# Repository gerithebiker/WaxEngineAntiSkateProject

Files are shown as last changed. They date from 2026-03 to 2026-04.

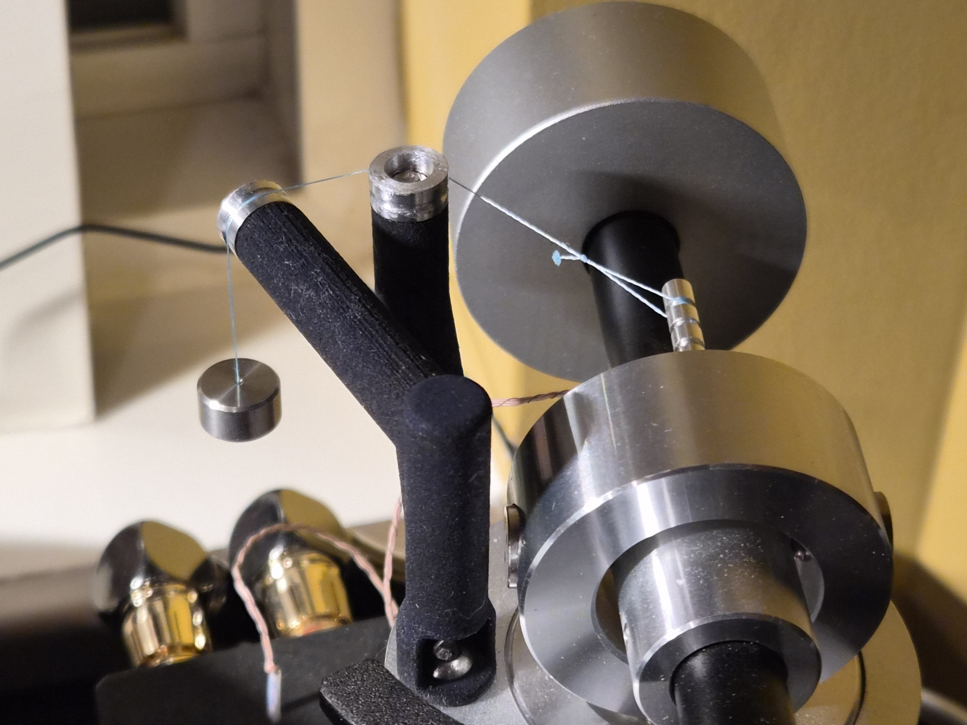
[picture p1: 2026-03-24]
images/completed.jpg

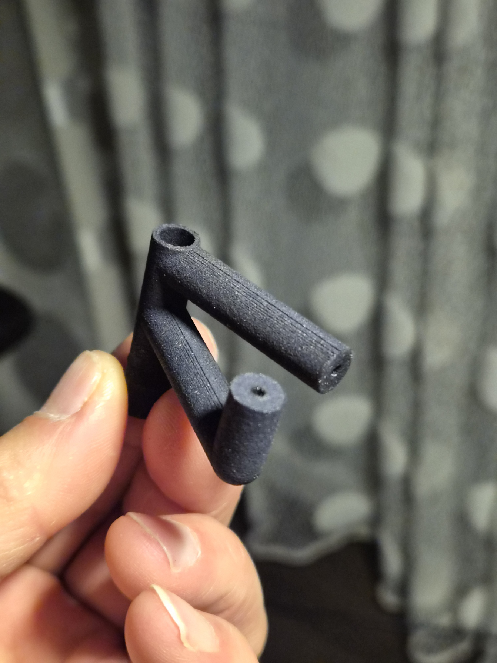
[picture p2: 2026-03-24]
images/housing.jpg

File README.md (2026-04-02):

# WaxEngineAntiSkateProject
3D printable anti-skate mechanism upgrade for the Opera Consonance Wax Engine turntable. Dual-pulley, ball-bearing design replacing the original flexible wire support.

# Opera Consonance Wax Engine Anti-Skate Upgrade (3D Printable)

A 3D-printable anti-skate mechanism upgrade for the Opera Consonance Wax Engine turntable.
This design replaces the original flexible wire support with a rigid, dual-pulley, ball-bearing system for smoother and more stable operation.

---

## 🔧 Why this upgrade?

The stock anti-skate mechanism uses a thin wire to hold the counterweight.
While it works in theory, in practice it tends to flex, bend, and introduce inconsistent behavior.

Typical issues:

* Wire bending under load
* Stick-slip motion (jerky movement)
* Unpredictable anti-skate force

This upgrade solves these problems with a mechanically simple but much more stable solution.

---

## ⚙️ Design overview

* Dual-pulley system for proper line guidance
* Ball bearings for near-zero friction
* Rigid printed housing (no flex under load)
* Compact design that fits the original geometry

The vertical pulley ensures proper alignment, while the horizontal pulley handles the load — eliminating angle-related inconsistencies.

---

## 🧵 Line options

Two approaches were tested:

### 1. Human hair (yes, really 😄)

* Extremely thin
* Minimal friction
* Hard to tie and inconsistent

### 2. Braided fishing line (recommended)

* Consistent diameter
* Easy(er...) to work with
* Very strong and stable

👉 Recommendation: use the thinnest braided line available.
👉 If you don't have a special fishing line cutter, then the best way to cut is using a torch lighter. Normal scissors, knifes will _not_ work!

---

## 🔩 Bearings

Shielded (ZZ) miniature ball bearings are used in this design.

Recommended size:
- Inner diameter: 2 mm  
- Outer diameter: 5 mm  
- Width: 2.5 mm  

These are commonly referred to as **MR52ZZ bearings** and are widely available from many suppliers. You need 2 pieces.

---

## 🔧 Shafts

The bearings are mounted on simple 2 mm shafts.

These can be:
- 2 mm steel rods  
- Cut sections of drill bits  
- Any straight, rigid 2 mm metal rod  

You need 1 piece of 20-22mm long, and one 17mm long.

Make sure the shaft fits snugly and keeps the bearings aligned. If the shafts feel loose, you can glue them in place.
Just be careful — once glued, they’re not coming out easily, so treat this as a final step.

---

## 🧱 Files included

* `/AntiSkatingOnePiece.FCStd` → full FreeCAD model
* `/stl/` → ready-to-print parts
* `/images/` → reference and assembly images

---

## 🖨️ Printing notes

* Material: First I used SLS (see pics), but the surface is not really smooth, but otherwise very good.  For the second print I used UTR imagine black resin.
* Layer height: standard (0.2 mm works fine)
* No special settings required

---

## 🧾 Printing services

If you don’t have access to a 3D printer, this design can be easily ordered from most online printing services.

I used a commercial printing service ([Xometry](https://www.xometry.com)) with standard PLA settings, printed in black PLA, and the parts worked well with minimal cleanup.
Services, like JLCPCB are using different coordinate as "up", so you might need to re-create the STL files.

---

## 🔩 Assembly notes

* The holes for bearing shafts are intentionally undersized
* Drill holes to **2 mm** during assembly
* This ensures proper fit despite printing tolerances

Make sure bearings rotate freely after installation.

---

## 🎯 Result

* Smooth, continuous movement
* No stiction
* No visible flex
* Stable and predictable anti-skate behavior

---

## 🧠 Notes

This is a simple mechanical improvement — no electronics, no complex tuning — just fixing a weak point in an otherwise excellent turntable.

---

## 📎 Related article

Full write-up and background:
👉 [Opera Consonance Wax Engine Anti-Skate Modification (DIY Fix), Blog post](https://geri-in-ny.blogspot.com/2026/03/opera-consonance-wax-engine-anti-skate.html)

---

## 🤘 License

CERN-OHL-S v2 — Strongly Reciprocal Open Hardware License.

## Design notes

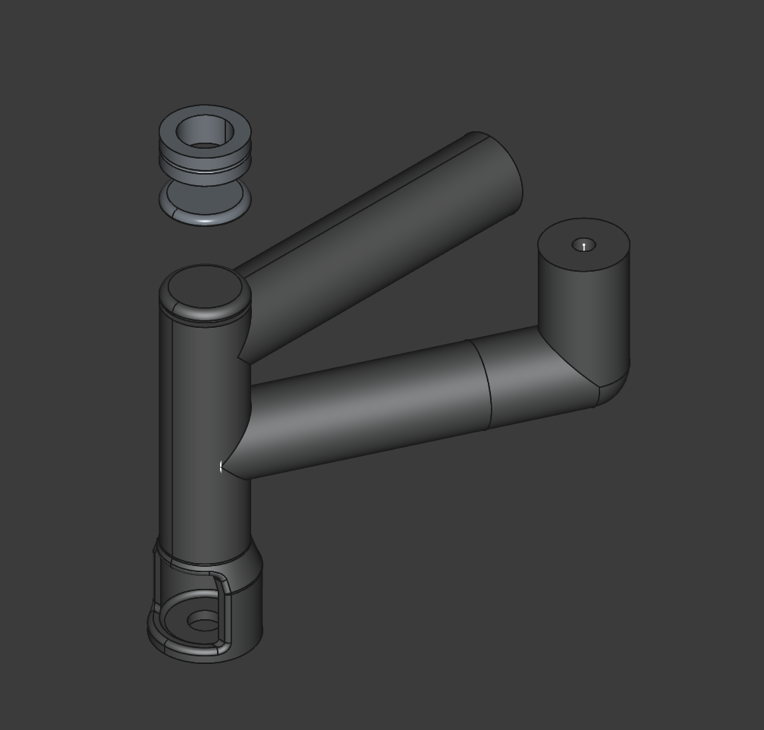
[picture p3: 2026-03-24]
images/AntiSkatingOnePiece.png

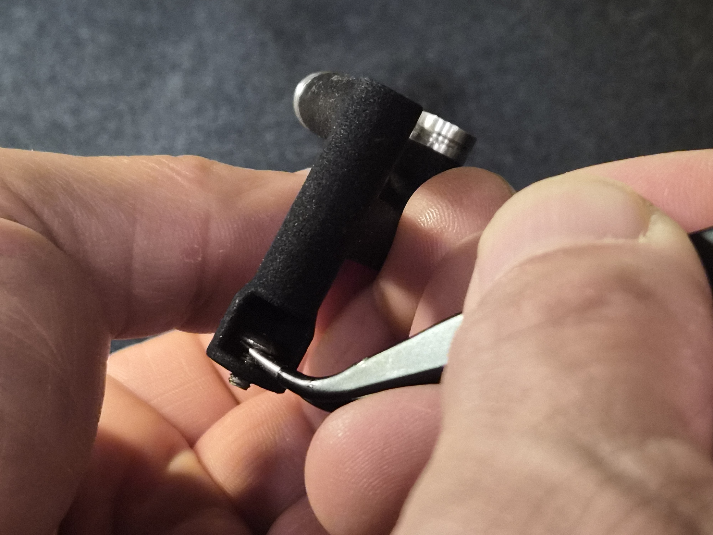
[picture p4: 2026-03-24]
images/insertingTheScrew.jpg

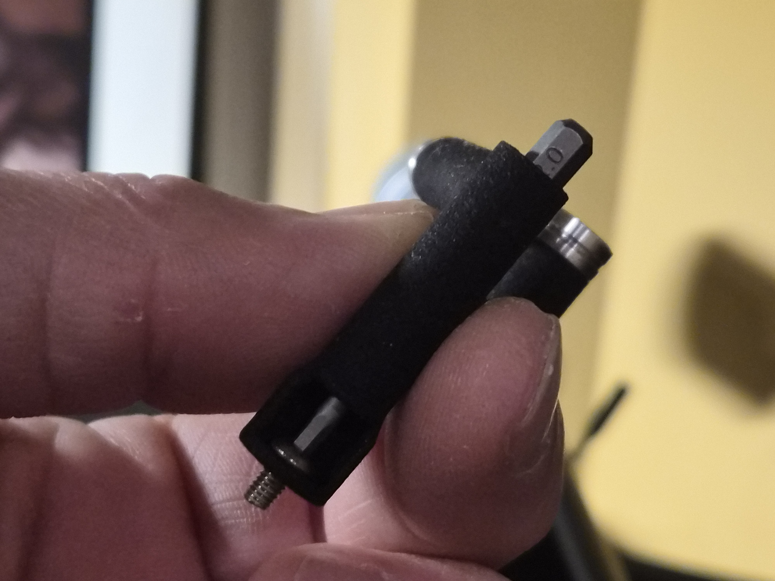
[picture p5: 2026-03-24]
images/allenKeyInPlace.jpg

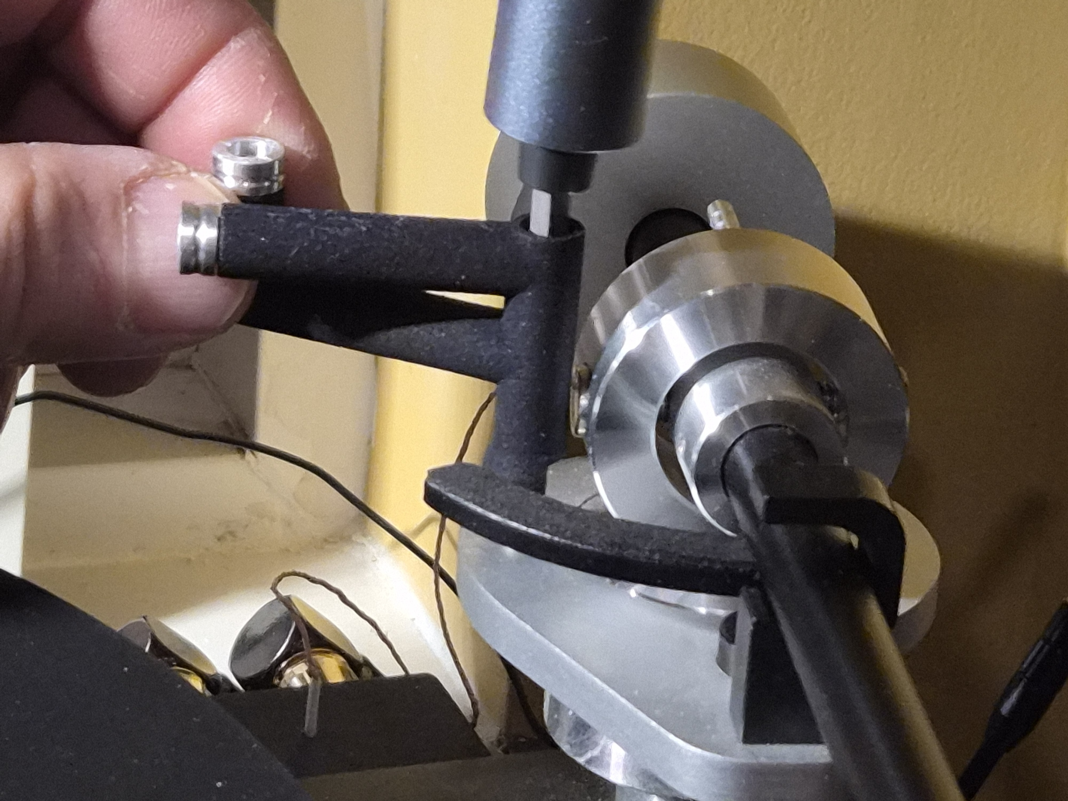
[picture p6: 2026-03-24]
images/securingTheHousing.jpg

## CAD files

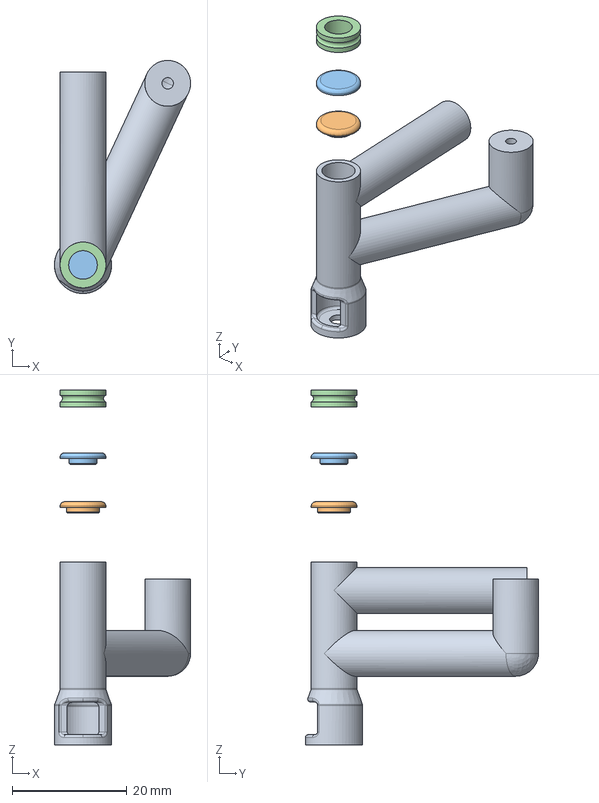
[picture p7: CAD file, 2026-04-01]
AntiSkatingOnePiece.FCStd
23.8 x 40.7 x 62.0 mm
Housing
HousingCap
PulleyCap
Pulley

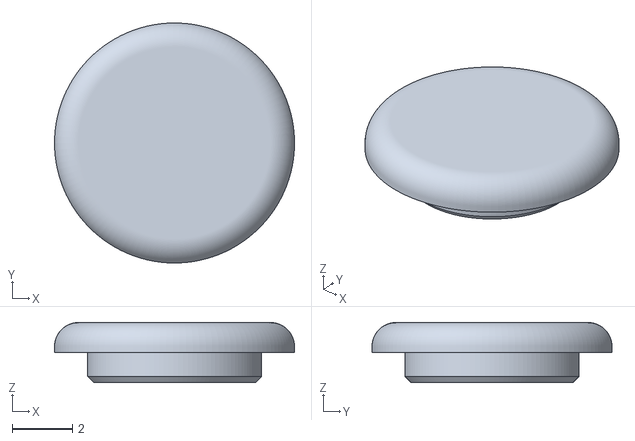
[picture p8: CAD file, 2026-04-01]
stl/AntiSkatingOnePiece-HousingCap.stl
8.00 x 8.00 x 2.00

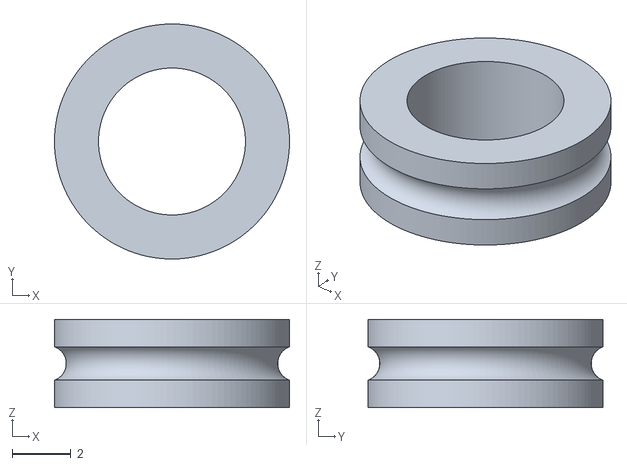
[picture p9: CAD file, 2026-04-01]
stl/AntiSkatingOnePiece-Pulley.stl
8.00 x 8.00 x 3.00

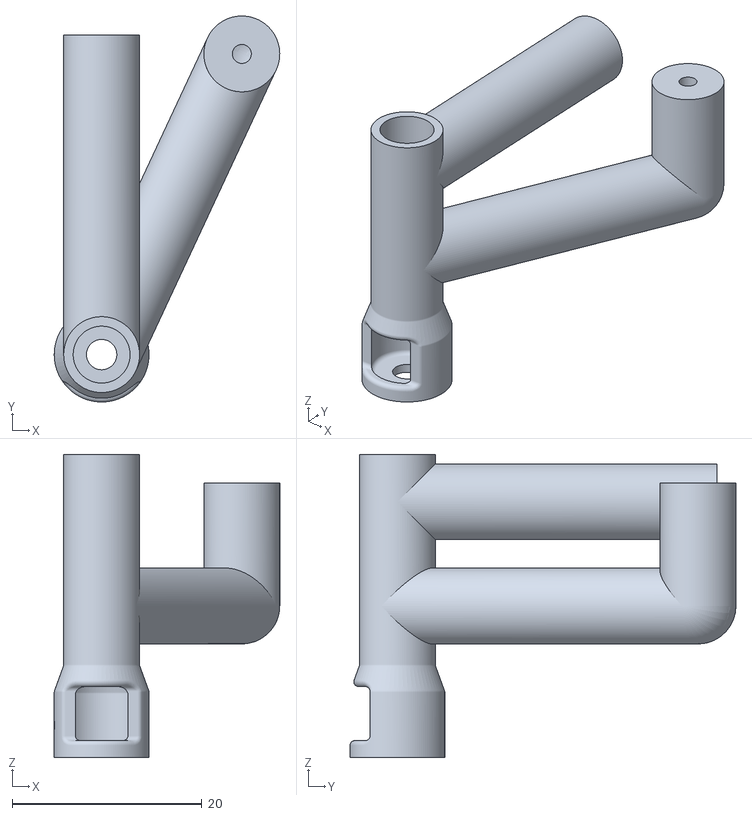
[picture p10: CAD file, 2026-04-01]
stl/AntiSkatingOnePiece-Housing.stl
23.8 x 40.7 x 32.0

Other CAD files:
stl/AntiSkatingOnePiece-PulleyCap.stl

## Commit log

2026-03-24 Enhance README with detailed upgrade information
    Expanded the README to include detailed upgrade information, design overview, line options, included files, printing and assembly notes, results, and licensing.
2026-03-24 First working version
    [AntiSkatingOnePiece-Housing.stl, AntiSkatingOnePiece-HousingCap.stl, AntiSkatingOnePiece-Pulley.stl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]
2026-03-24 Updated file structure
    [AntiSkatingOnePiece-Housing.stl, AntiSkatingOnePiece-HousingCap.stl, AntiSkatingOnePiece-Pulley.stl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]
2026-03-24 Updated file structure v 2.
    [AntiSkatingOnePiece-Housing.stl, AntiSkatingOnePiece-HousingCap.stl, AntiSkatingOnePiece-Pulley.stl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]
2026-03-24 Added images, increased the base hole
    [AntiSkatingOnePiece.FCStd]
2026-03-24 Add printing services section to README
    Added section on printing services and personal experience with Xometry.
2026-03-24 Update README with bearings and shafts details
    Added sections for bearings and shafts with specifications and assembly notes.
2026-03-24 Clarify bearing shaft description in README
    Mistakenly wrote that the shafts are undersized, but it is the holes for the shafts...
2026-03-31 Revision one
    [AntiSkatingOnePiece-Housing.stl, AntiSkatingOnePiece-HousingCap.stl, AntiSkatingOnePiece-PulleyCap.stl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]
2026-04-02 Revise printing notes and STL file compatibility
    Updated material description for printing notes and added information about STL file compatibility with different services.
